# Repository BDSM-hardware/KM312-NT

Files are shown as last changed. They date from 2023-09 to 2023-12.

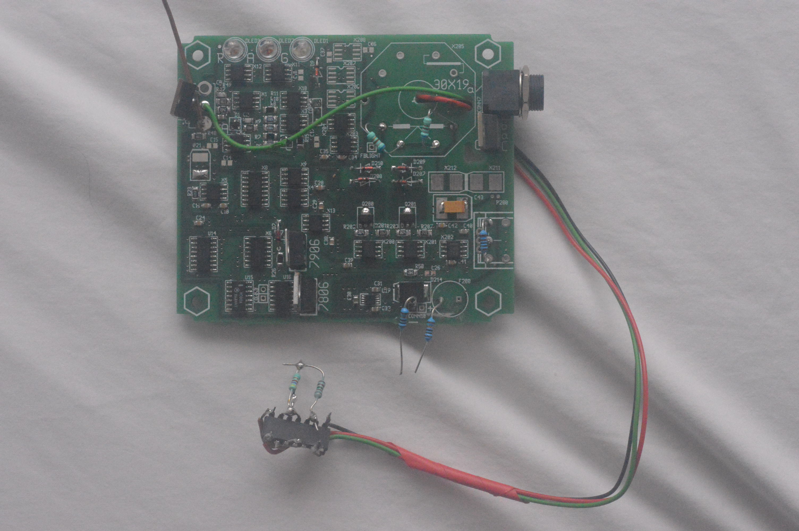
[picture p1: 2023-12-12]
Photos/DSC_0011.JPG

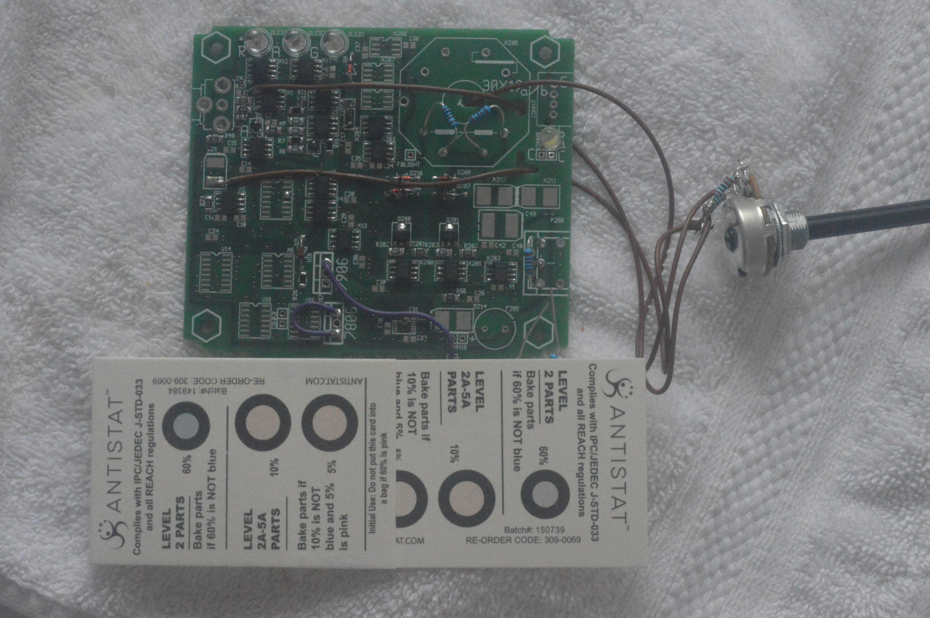
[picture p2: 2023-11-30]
Photos/DSC_0010.JPG

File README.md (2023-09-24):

The KM312-NT project implements the audio 3 mode of the ET312 or its clones such as the MK312.

It is a PCB of about 8x8cm that contains everything (including the power supply). One have to build as many as needed boards according to the desired number of channels.

It works with a supply around 10V. That can provided by 6 AA type batteries 1.5V or 8 NiMh AA type 1.5V or a single 9V battery.

It uses the PulsesGene project from ElecGeek user, here on Github. It adds the voltage to current converter and the transformer.

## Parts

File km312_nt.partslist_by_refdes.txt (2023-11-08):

.START
..refdes	device	value	tolerance	comment	footprint	quantity
C10	CAPACITOR	22nF	20%	/	0805	1
C11	CAPACITOR	22nF	20%	/	0805	1
C12	CAPACITOR	22nF	20%	/	0805	1
C13	CAPACITOR	22nF	20%	/	0805	1
C14	CAPACITOR	22nF	20%	/	0805	1
C15	CAPACITOR	22nF	20%	/	0805	1
C16	CAPACITOR	22nF	20%	/	0805	1
C17	CAPACITOR	22nF	20%	/	0805	1
C18	CAPACITOR	22nF	20%	/	0805	1
C19	CAPACITOR	22nF	20%	/	0805	1
C2	CAPACITOR	470pF	10%	/	0805	1
C20	POLARIZED_CAPACITOR	22uF	20%	/	EIA6032	1
C201	POLARIZED_CAPACITOR	1uF	20%	50V tantale	EIA3216	1
C202	CAPACITOR	100pF	2%	/	0805	1
C203	CAPACITOR	100pF	2%	/	0805	1
C21	POLARIZED_CAPACITOR	22uF	20%	/	EIA6032	1
C22	CAPACITOR	22nF	20%	/	0805	1
C23	CAPACITOR	22nF	20%	/	0805	1
C24	CAPACITOR	22nF	20%	/	0805	1
C25	CAPACITOR	1uF	5%	/	0805	1
C26	CAPACITOR	100pF	2%	/	0805	1
C28	CAPACITOR	22nF	20%	/	0805	1
C29	CAPACITOR	22nF	20%	/	0805	1
C3	CAPACITOR	150nF	5%	/	0805	1
C30	CAPACITOR	1uF	20%	/	0805	1
C31	CAPACITOR	2.2uF	20%	/	0805	1
C32	CAPACITOR	2.2uF	20%	/	0805	1
C34	CAPACITOR	22nF	20%	/	0805	1
C35	CAPACITOR	22nF	20%	/	0805	1
C36	CAPACITOR	22nF	20%	/	0805	1
C37	CAPACITOR	22nF	20%	/	0805	1
C38	CAPACITOR	22nF	20%	/	0805	1
C39	CAPACITOR	22nF	20%	/	0805	1
C4	CAPACITOR	681pF	5%	/	0805	1
C40	CAPACITOR	22nF	20%	/	0805	1
C41	CAPACITOR	22nF	20%	/	0805	1
C42	CAPACITOR	22nF	20%	/	0805	1
C43	POLARIZED_CAPACITOR	22uF	20%	50V	EIA7343	1
C44	CAPACITOR	220nF	20%	/	0805	1
C6	CAPACITOR	470pF	5%	/	0805	1
C7	CAPACITOR	4.7uF	5%	MLCC 1206	1206	1
C8	CAPACITOR	470pF	5%	/	0805	1
C9	CAPACITOR	33pF	5%	/	0805	1
CONN10	CONNECTOR_2	unknown	unknown	unknown	unknown	1
CONN3	CONNECTOR_2	unknown	unknown	unknown	SIP2N	1
CONN4	CONNECTOR_3	unknown	/	unknown	unknown	1
CONN5	CONNECTOR_4	unknown	/	/	unknown	1
CONN7	CONNECTOR_4	unknown	unknown	unknown	SIP4N	1
CONN8	CONNECTOR_3	unknown	unknown	unknown	SIP3N	1
CONN9	CONNECTOR_1	unknown	unknown	unknown	SIP1N	1
D10	DIODE	MURS480ET3G	/	/	DO214	1
D11	DIODE	MURS480ET3G	/	/	DO214	1
D1_1	DIODE	BAT54AW	/	/	sot23	1
D1_2	DIODE	BAT54AW	/	/	sot23	1
D200	DIODE	BAT54AW	/	/	sot23	1
D201	DIODE	BAT54AW	/	/	sot23	1
D207	DIODE	1N4148	/	/	300mil	1
D208	DIODE	1N4148	/	/	300mil	1
D209	DIODE	1N4148	/	/	300mil	1
D210	DIODE	1N4148	/	/	300mil	1
D211	DIODE	BAT54AW	/	Only full FB	sot23	1
D212	DIODE	BAT54AW	/	Only full FB	sot23	1
D213	DIODE	BAT54AW	/	/	sot23	1
D214	DIODE	MURS480ET3G	/	/	DO214	1
D215	DIODE	MURS480ET3G	/	/	DO214	1
D2_1	DIODE	BAT54CW	/	/	sot23	1
D2_2	DIODE	BAT54CW	/	/	sot23	1
D5_1	DIODE	BAT54CW	/	/	sot23	1
D6_1	DIODE	BAT54AW	/	/	sot23	1
D6_2	DIODE	BAT54AW	/	/	sot23	1
D7	DIODE	1N4148	/	/	300mil	1
D9	DIODE	1N4148	/	/	300mil	1
DLED1	D	C503B-GBN or GBS	/	green	5mm	1
DLED2	D	C503B-ABN or ABS	/	amber	5mm	1
DLED3	D	C503B-RBN or RBS	/	red	5mm	1
F200	FUSE	mA	/	/	200mil	1
FBLIGHT	CONNECTOR_1	unknown	unknown	unknown	SIP1N	1
P200	VARIABLE_RESISTOR	1K	20%	P11VK	2x200mil	1
Q200	NPN_TRANSISTOR	DXT651	/	/	sot89-3	1
Q201	NPN_TRANSISTOR	DXT651	/	/	sot89-3	1
R1	RESISTOR	10K	2%	/	1206	1
R10	RESISTOR	100K	1%	/	1206	1
R11	RESISTOR	140K	1%	/	1206	1
R12	RESISTOR	1K	2%	/	1206	1
R13	RESISTOR	140K	2%	/	1206	1
R14	RESISTOR	100	10%	/	1206	1
R15	RESISTOR	348K	2%	/	1206	1
R16	RESISTOR	10K	1%	/	1206	1
R17	RESISTOR	10K	1%	/	1206	1
R18	RESISTOR	10K	1%	/	1206	1
R19	RESISTOR	10K	1%	/	1206	1
R2	RESISTOR	40.2K	2%	/	1206	1
R20	RESISTOR	2.21K	1%	/	1206	1
R200	RESISTOR	1.5K	10%	/	1206	1
R201	RESISTOR	22.1K	2%	/	1206	1
R202	RESISTOR	2.87K	2%	/	1206	1
R203	RESISTOR	3.16	1%	Depends output level	2512	1
R204	RESISTOR	1K	2%	/	1206	1
R205	RESISTOR	4.75K	2%	/	1206	1
R206	RESISTOR	1.5K	10%	/	1206	1
R207	RESISTOR	22.1K	2%	/	1206	1
R208	RESISTOR	2.87K	2%	/	1206	1
R209	RESISTOR	3.16	1%	Depends output level	2512	1
R21	RESISTOR	34.0K	1%	/	1206	1
R210	RESISTOR	1K	2%	/	1206	1
R211	RESISTOR	4.75K	2%	/	1206	1
R212	RESISTOR	22.1K	1%	/	1206	1
R213	RESISTOR	22.1K	1%	/	1206	1
R214	RESISTOR	100	30%	For test	1206	1
R215	RESISTOR	1G	30%	For Spice	2706	1
R216	RESISTOR	22.1K	10%	/	1206	1
R217	RESISTOR	1K	10%	/	1206	1
R218	RESISTOR	22.1K	10%	/	1206	1
R219	RESISTOR	22.1K	10%	/	1206	1
R220	RESISTOR	750K	2%	/	1206	1
R221	RESISTOR	100K	2%	/	1206	1
R222	RESISTOR	750K	2%	/	1206	1
R223	RESISTOR	100K	2%	/	1206	1
R224	RESISTOR	100K	10%	/	1206	1
R225	RESISTOR	750K	10%	/	1206	1
R226	RESISTOR	750K	10%	/	1206	1
R228	RESISTOR	750K	10%	/	1206	1
R229	RESISTOR	750K	10%	/	1206	1
R23	RESISTOR	1K	2%	/	1206	1
R230	RESISTOR	100K	2%	/	1206	1
R231	RESISTOR	100K	2%	/	1206	1
R232	RESISTOR	100K	2%	/	1206	1
R233	RESISTOR	750K	10%	/	1206	1
R234	RESISTOR	750K	10%	/	1206	1
R235	RESISTOR	1meg	2%	/	1206	1
R236	RESISTOR	1meg	2%	/	1206	1
R237	RESISTOR	470	2%	/	1206	1
R24	RESISTOR	348K	2%	/	1206	1
R25	RESISTOR	10K	10%	/	1206	1
R26	RESISTOR	6.19K	10%	/	1206	1
R29	RESISTOR	6.19K	10%	peak display only	1206	1
R30	RESISTOR	750K	2%	/	1206	1
R31	RESISTOR	15.4K	2%	/	1206	1
R32	RESISTOR	15.4K	2%	/	1206	1
R33	RESISTOR	15.4K	2%	/	1206	1
R34	RESISTOR	750K	2%	/	1206	1
R35	RESISTOR	750K	2%	/	1206	1
R36	RESISTOR	348K	1%	/	1206	1
R37	RESISTOR	51.1K	1%	/	1206	1
R38	RESISTOR	348K	1%	/	1206	1
R39	RESISTOR	51.1K	1%	/	1206	1
R40	RESISTOR	1K	2%	/	1206	1
R41	RESISTOR	unknown	2%	Lower frequency	1206	1
R42	RESISTOR	unknown	2%	If adjustable	1206	1
R43	RESISTOR	10K	2%	avg. display only	1206	1
R44	RESISTOR	1K	10%	/	1206	1
R45	RESISTOR	140K	10%	/	1206	1
R46	RESISTOR	10K	10%	/	1206	1
R47	RESISTOR	15.4K	10%	/	1206	1
R48	RESISTOR	40.2K	2%	/	1206	1
R49	RESISTOR	40.2K	2%	/	1206	1
R5	RESISTOR	1K	2%	/	1206	1
R50	RESISTOR	10K	1%	/	1206	1
R6	RESISTOR	100K	10%	/	1206	1
R7	RESISTOR	140K	1%	/	1206	1
R8	RESISTOR	100K	1%	/	1206	1
R9	RESISTOR	6.19K	2%	/	1206	1
U13	74163	74HC163	/	or 161	SOIC16	1
U14	74163	74HC163	/	or 160, 161, 162	SOIC16	1
U15	7400	74HC00	/	/	SOIC14	1
U16	7473	74HC73	/	/	SOIC14	1
U17	7806	7806	/	/	TO220	1
U18	7906	7906	/	/	TO220	1
U19	njw4191	NJW4191	/	/	MSOP8	1
U7	7402	74HC02	/	/	SOIC14	1
X1	LM741	TLV07	/	/	SOIC8	1
X10	LM741	TLV07	/	/	SOIC8	1
X11	LM741	TLV07	/	/	SOIC8	1
X12	LM741	TLV07	/	/	SOIC8	1
X13	LM741	OPA196IDR	/	/	SOIC8	1
X2	LM741	TLV07	/	/	SOIC8	1
X200	LM741	OPA196IDR	/	/	SOIC8	1
X201	LM741	OPA196IDR	/	/	SOIC8	1
X202	LM741	OPA196IDR	/	/	SOIC8	1
X203	LM741	TLV07	/	/	SOIC8	1
X204	LM741	TLV07	/	/	SOIC8	1
X205	TRANSFORMER 	unknown	unknown	unknown	Siemens 30x19	1
X206	LM741	TLV07	/	/	SOIC8	1
X207	LM741	TLV07	/	/	SOIC8	1
X208	LM741	TLV07	/	/	SOIC8	1
X209	ZENER_DIODE	unknown	/	see_README	DO214	1
X210	ZENER_DIODE	unknown	/	see_README	DO214	1
X211	ZENER_DIODE	unknown	/	see_README	DO214	1
X212	ZENER_DIODE	unknown	/	see_README	DO214	1
X3	LM741	TLV07	/	/	SOIC8	1
X4	LM741	TLV07	/	/	SOIC8	1
X5	LM741	TLV07	/	/	SOIC8	1
X6	7473	74HC73	/	/	SOIC14	1
X8	744053	74HC4053	/	/	SOIC16	1
X8_1	4053	74HC4053	/	/	SOIC16	1
X8_2	4053	74HC4053	/	/	SOIC16	1
X8_3	4053	74HC4053	/	/	SOIC16	1
X9	LM741	OPA196IDR	/	/	SOIC8	1
.END

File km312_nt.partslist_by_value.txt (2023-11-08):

.START
..device	value	tolerance	comment	footprint	quantity	refdes
4053	74HC4053	/	/	SOIC16	3	X8_1 X8_2 X8_3
7400	74HC00	/	/	SOIC14	1	U15
7402	74HC02	/	/	SOIC14	1	U7
74163	74HC163	/	or 161	SOIC16	1	U13
74163	74HC163	/	or 160, 161, 162	SOIC16	1	U14
744053	74HC4053	/	/	SOIC16	1	X8
7473	74HC73	/	/	SOIC14	2	U16 X6
7806	7806	/	/	TO220	1	U17
7906	7906	/	/	TO220	1	U18
CAPACITOR	100pF	2%	/	0805	3	C202 C203 C26
CAPACITOR	150nF	5%	/	0805	1	C3
CAPACITOR	1uF	20%	/	0805	1	C30
CAPACITOR	1uF	5%	/	0805	1	C25
CAPACITOR	2.2uF	20%	/	0805	2	C31 C32
CAPACITOR	220nF	20%	/	0805	1	C44
CAPACITOR	22nF	20%	/	0805	24	C10 C11 C12 C13 C14 C15 C16 C17 C18 C19 C22 C23 C24 C28 C29 C34 C35 C36 C37 C38 C39 C40 C41 C42
CAPACITOR	33pF	5%	/	0805	1	C9
CAPACITOR	4.7uF	5%	MLCC 1206	1206	1	C7
CAPACITOR	470pF	10%	/	0805	1	C2
CAPACITOR	470pF	5%	/	0805	2	C6 C8
CAPACITOR	681pF	5%	/	0805	1	C4
CONNECTOR_1	unknown	unknown	unknown	SIP1N	2	CONN9 FBLIGHT
CONNECTOR_2	unknown	unknown	unknown	unknown	1	CONN10
CONNECTOR_2	unknown	unknown	unknown	SIP2N	1	CONN3
CONNECTOR_3	unknown	/	unknown	unknown	1	CONN4
CONNECTOR_3	unknown	unknown	unknown	SIP3N	1	CONN8
CONNECTOR_4	unknown	/	/	unknown	1	CONN5
CONNECTOR_4	unknown	unknown	unknown	SIP4N	1	CONN7
D	C503B-ABN or ABS	/	amber	5mm	1	DLED2
D	C503B-GBN or GBS	/	green	5mm	1	DLED1
D	C503B-RBN or RBS	/	red	5mm	1	DLED3
DIODE	1N4148	/	/	300mil	6	D207 D208 D209 D210 D7 D9
DIODE	BAT54AW	/	/	sot23	9	D1_1 D1_2 D200 D201 D211 D212 D213 D6_1 D6_2
DIODE	BAT54CW	/	/	sot23	3	D2_1 D2_2 D5_1
DIODE	MURS480ET3G	/	/	DO214	4	D10 D11 D214 D215
FUSE	mA	/	/	200mil	1	F200
LM741	OPA196IDR	/	/	SOIC8	5	X13 X200 X201 X202 X9
LM741	TLV07	/	/	SOIC8	13	X1 X10 X11 X12 X2 X203 X204 X206 X207 X208 X3 X4 X5
njw4191	NJW4191	/	/	MSOP8	1	U19
NPN_TRANSISTOR	DXT651	/	/	sot89-3	2	Q200 Q201
POLARIZED_CAPACITOR	1uF	20%	50V tantale	EIA3216	1	C201
POLARIZED_CAPACITOR	22uF	20%	/	EIA6032	2	C20 C21
POLARIZED_CAPACITOR	22uF	20%	50V	EIA7343	1	C43
RESISTOR	1.5K	10%	/	1206	2	R200 R206
RESISTOR	100	10%	/	1206	1	R14
RESISTOR	100	30%	For test	1206	1	R214
RESISTOR	100K	1%	/	1206	2	R10 R8
RESISTOR	100K	10%	/	1206	2	R224 R6
RESISTOR	100K	2%	/	1206	5	R221 R223 R230 R231 R232
RESISTOR	10K	1%	/	1206	5	R16 R17 R18 R19 R50
RESISTOR	10K	10%	/	1206	2	R25 R46
RESISTOR	10K	2%	/	1206	1	R1
RESISTOR	10K	2%	avg. display only	1206	1	R43
RESISTOR	140K	1%	/	1206	2	R11 R7
RESISTOR	140K	10%	/	1206	1	R45
RESISTOR	140K	2%	/	1206	1	R13
RESISTOR	15.4K	10%	/	1206	1	R47
RESISTOR	15.4K	2%	/	1206	3	R31 R32 R33
RESISTOR	1G	30%	For Spice	2706	1	R215
RESISTOR	1K	10%	/	1206	2	R217 R44
RESISTOR	1K	2%	/	1206	6	R12 R204 R210 R23 R40 R5
RESISTOR	1meg	2%	/	1206	2	R235 R236
RESISTOR	2.21K	1%	/	1206	1	R20
RESISTOR	2.87K	2%	/	1206	2	R202 R208
RESISTOR	22.1K	1%	/	1206	2	R212 R213
RESISTOR	22.1K	10%	/	1206	3	R216 R218 R219
RESISTOR	22.1K	2%	/	1206	2	R201 R207
RESISTOR	3.16	1%	Depends output level	2512	2	R203 R209
RESISTOR	34.0K	1%	/	1206	1	R21
RESISTOR	348K	1%	/	1206	2	R36 R38
RESISTOR	348K	2%	/	1206	2	R15 R24
RESISTOR	4.75K	2%	/	1206	2	R205 R211
RESISTOR	40.2K	2%	/	1206	3	R2 R48 R49
RESISTOR	470	2%	/	1206	1	R237
RESISTOR	51.1K	1%	/	1206	2	R37 R39
RESISTOR	6.19K	10%	/	1206	1	R26
RESISTOR	6.19K	10%	peak display only	1206	1	R29
RESISTOR	6.19K	2%	/	1206	1	R9
RESISTOR	750K	10%	/	1206	6	R225 R226 R228 R229 R233 R234
RESISTOR	750K	2%	/	1206	5	R220 R222 R30 R34 R35
RESISTOR	unknown	2%	Lower frequency	1206	1	R41
RESISTOR	unknown	2%	If adjustable	1206	1	R42
TRANSFORMER 	unknown	unknown	unknown	Siemens 30x19	1	X205
VARIABLE_RESISTOR	1K	20%	P11VK	2x200mil	1	P200
ZENER_DIODE	unknown	/	see_README	DO214	4	X209 X210 X211 X212
.END

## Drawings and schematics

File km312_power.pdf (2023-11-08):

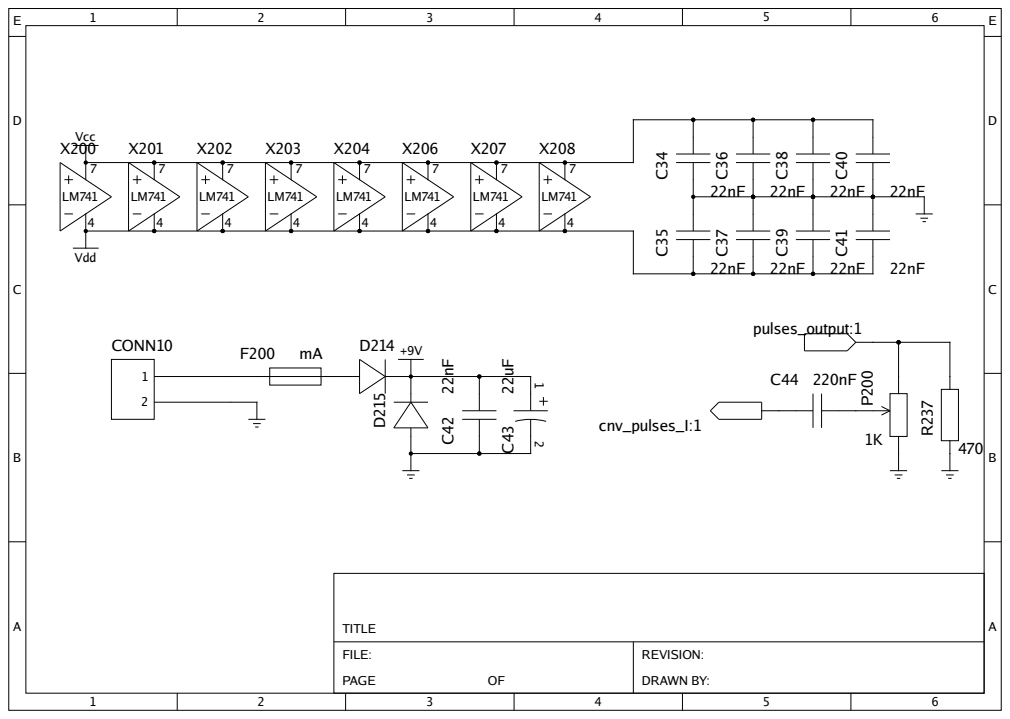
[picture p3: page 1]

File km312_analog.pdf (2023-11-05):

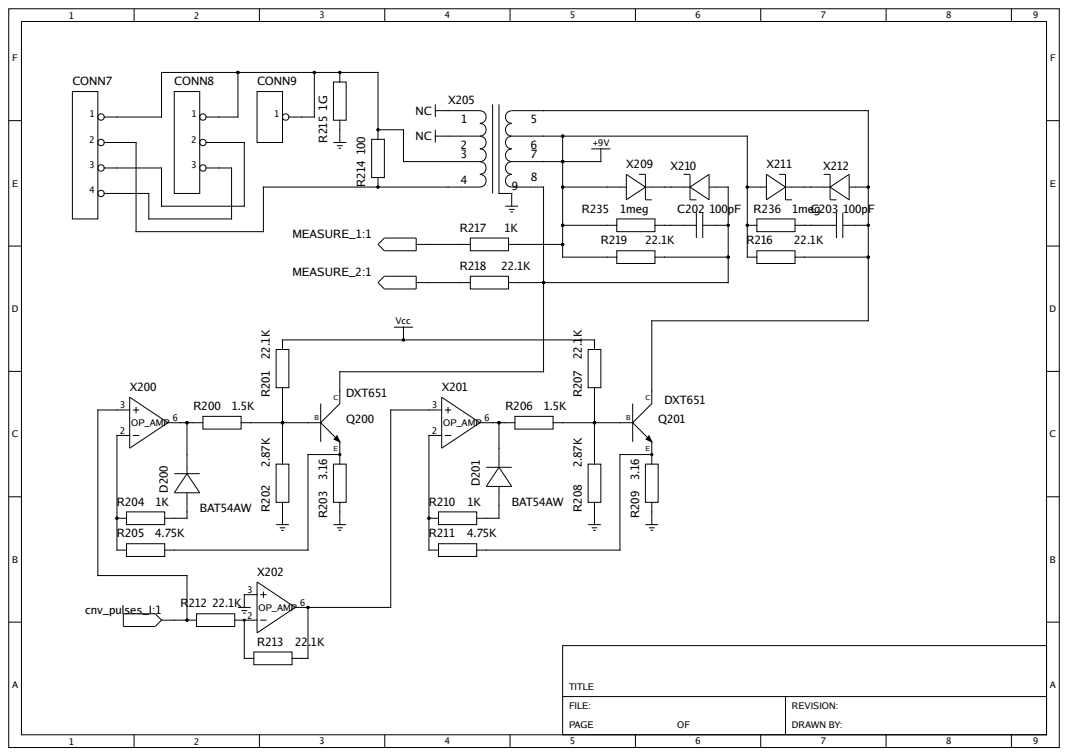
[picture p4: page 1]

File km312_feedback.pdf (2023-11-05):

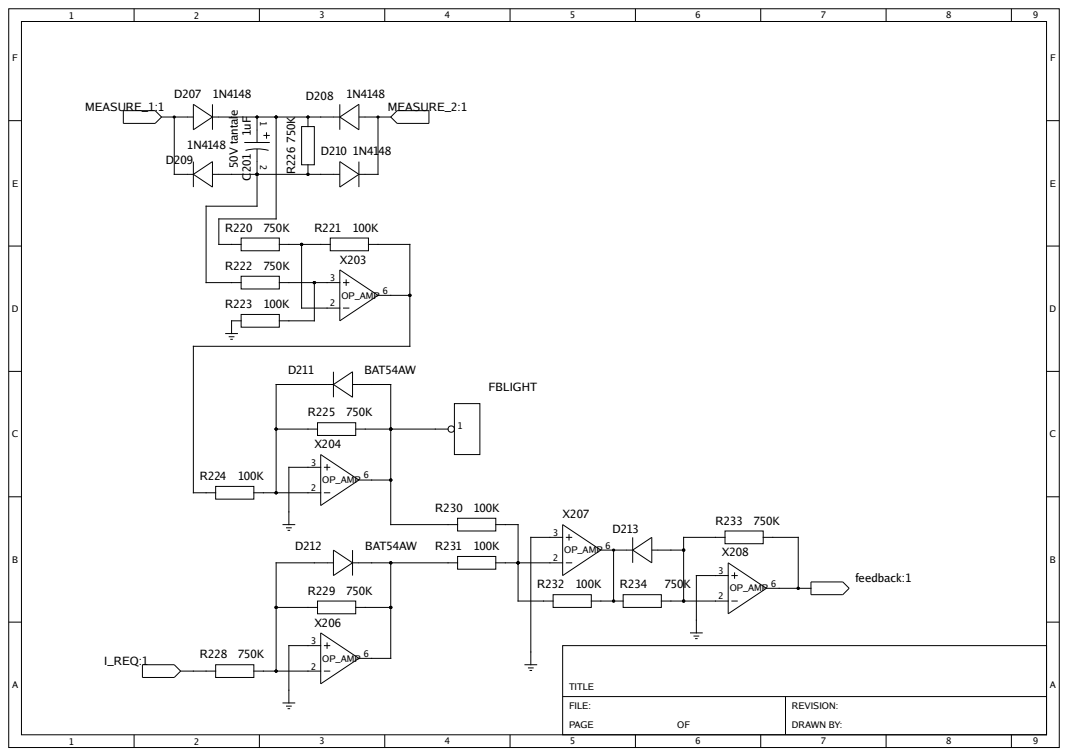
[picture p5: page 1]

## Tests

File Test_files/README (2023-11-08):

This folder is not really a part of this project.

It contains test files to generate audio using the project https://github.com/ElecGeek/MultiSignalGene

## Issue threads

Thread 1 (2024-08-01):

Ouput connector pinout wrong

BDSM-hardware, 2024-08-01:
My footprint is wrong. The pinout is 1, 4, 2, 3 rather than 4, 3, 2, 1

BDSM-hardware, 2024-08-04:
Fixed in the last commit

Closed 2024-08-04.

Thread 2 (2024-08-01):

Extented feedback wrong

BDSM-hardware, 2024-08-01:
The extended feedback was design in order to reserve the room on the PCB for the version 2. More design was needed, especially to avoid a red indication when the level is low ( 0 divide by 0 ).

Fortunately a light feedback pin has been added.
This is the only one option.

Indeed, due to the latency, the V and I pulses are not superposed. Then their amplitudes has to be detected. It has been done correctly for the I but for the V, there is no point to get it. Before the 74HC analogue switch, the value is available, but the volume button is after.

BDSM-hardware, 2024-08-01:
Won't fix. The version 2 out as that would have need to redesign the PCB in a new box.

BDSM-hardware, 2024-08-01:
Wait for version 3

BDSM-hardware, 2024-08-01:
Won't fix. Wait for version 3

BDSM-hardware, 2024-08-01:
Won't fix. Wait for version 3

Closed 2024-08-01.

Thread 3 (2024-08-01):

Version 3

BDSM-hardware, 2024-08-01:
A new version is going to use a Lattice FPGA and MCP3919 converters.

The feasibility is under investigation. This version may include 4 channels on a board using the same box (but not the same cut out).
Configurations can be wired as 2 bi-phase or one triphase ans one single, or 1 quadriphase.

However, a programming device is required.

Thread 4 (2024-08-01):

Extended feedback is wrong

BDSM-hardware, 2024-08-01:
The extended feedback has been implemented in order to reserve the room on the PCB. More design was needed to ensure the display is always green at low level.

Since there are some latencies, the V and the I pulse are not superposed. Then the amplitude has to be detected. It is properly done for the I, but one does have it for the V. Indeed the pulses are generated against an amplitude, but the volume button is after the analogue circuit.

Closed 2024-08-01.

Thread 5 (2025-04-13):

Fatal bug in the power supply

BDSM-hardware, 2025-04-13:
The circuit NJW4191 is very nice, as it accepts input voltages of more than 14.4V (the high AGM or lead battery voltage).
It should work at all time as it is the negative power supply of the analogue part.

However this part of the circuit has a maximum input voltage of 6V.

I made many tests on 2 boards. Last week the circuit of one of them burned.

It impacts only the master branch as the digital one is not planned to have a negative power supply.

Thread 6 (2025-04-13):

MAJOR BUG in the power supply

BDSM-hardware, 2025-04-13:
The circuit NJW4191 is very nice, as it accepts input voltages of more than 14.4V (the high AGM or lead battery voltage).

This circuit has an ON/OFF input
It should work at all time as it is the negative power supply of the analogue part. Then the pin is always ON

However the ON/OFF pin has a maximum input voltage of 6V.

I made many tests on 2 boards. Last week the circuit of one of them burned.

It impacts only the master branch as the digital one is not planned to have a negative power supply.

BDSM-hardware, 2025-05-11:
Fixed. The box has been tested for 2 hours the 10th of may.

Closed 2025-05-11.

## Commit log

2023-09-24 Initial and very early version
    [convert_test.sch, km312_analog.sch, transfo.sch]
2023-10-01 Schematic diagram close to the RC
    Initial version of the feedback, checking the voltage.
    [km312_analog.sch]
2023-10-07 More work
    PCB is going forward
    Components attributes improved in the schematics
    [convert_test.sch, km312_analog.sch, transfo.sch]
2023-10-07 ... and the schematics
2023-10-15 More work and new feedback feature
    [km312_analog.sch, km312_feedback.sch, km312_feedback_test.sch]
2023-10-21 PCB work
    PCB meca and box meca improved
    Feedback
    Other PCB work
    Some fixes in the PCB
    [convert_test.sch, km312_analog.sch, km312_feedback.sch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]
2023-11-05 First RC candidate
    PCB is finished
    More minor fixes has been done
    See more details in the README.pcb files
    [PCB_CC.bottom.gbr, PCB_CC.bottommask.gbr, PCB_CC.bottompaste.gbr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]
2023-11-08 Some fixes
    See in the README.pcb file
    [km312_power.sch]
2023-11-30 Partial mount and DC test
    While shunting some capacitors and setting to a couple of mA Output,
    this test, sending -max to +max input DC generates correct LED display and correct output current.
    The through hole for the 1N4148 is a little big small. This is going to be fixed.
    Next: cut the circuit, mount the supplies, mount the logic,
    build a Q&D input oscillator and test using a scope.
2023-12-12 First dynamic test
    Using a Q&D square generator (and still use the "dummy" transformer),
    a test of the board has been made at low current.
    CHANGES:
    * PCB separated from another one (without any relation), charge pump and the voltage regulator has been mounted.
    * R50 decreased down-to 3.40K
    * 1N4148 footprint changed for a diameter hole 10% higher
    * silk data moved outside the vias. I expected to order a via fill up, but it is very expensive.
    * minor changes in the outline.
    TODO:
    * validation and simulation of the transformer.
    * order some missing components, especially the zenners and C43.
    * investigate the overshoot. decoupling? higher R203 and R209?
    Problem:
    * Amphenol looks like to dis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
    [PCB_CC.bottom.gbr, PCB_CC.bottommask.gbr, PCB_CC.bottompaste.gbr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]
